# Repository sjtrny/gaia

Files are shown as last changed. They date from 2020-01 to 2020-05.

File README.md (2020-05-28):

# gaia

Gaia is a custom built environment sensor. This repository contains:
- parts list
- required software and setup instructions

## Overview

Gaia provides the following data:
- Ambient Lux
- Local Temperature (near device)
- Local Humidity
- Local Pressure
- Local Gas Resistance (Air Quality)
- Remote Temperature (away from device)

Two I2C sensor are used to collect this data:
- VEML770 (ambient lux)
- BME680 (local readings)
- DS18B20 waterproof (remote temp)

Temperature and Humidity are displayed on an Adafruit LCD.

Gaia runs on [ESPHome](https://esphome.io). See `gaia.yml`  for the configuration of the device.

## AdaFruit RGB LCD Shield

ESPHome does not have an official component for the AdaFruit RB LCD Sheild so I have written a component
for it which you can find in the `custom_components`  folder.

## VEML7700 Support

ESPHome does not have an official component for the VEMl7700 device, so I have written a small device wrapper `veml7700.h`, which leverages the "Adafruit VEML7700 Library".

## Parts List

The parts list can be found in the `parts.xlsx` file.

## Hardware and Wiring

TODO

## Instructions

1. Create virtual environment and install dependencies

```
./setup.sh
```

2. Activate virtual environment

```
source venv/bin/activate
```

3. Add wifi details to  `gaia.yml`

4. Plug in ESP32 via USB

5. Compile and upload to ESP32

```
		esphome gaia.yml run
```

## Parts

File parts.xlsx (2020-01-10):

Unit Price | Count | Total | Name | Link
$14.99 | 1 | $14.99 | ESP32 | https://www.ebay.com.au/itm/AU-ESP-WROOM-32-ESP32-ESP32S-2-4GHz-WiFi-Bluetooth-Development-Board-for-Arduino/303428770355
$36.00 | 1 | $36.00 | Pimoroni BME680 Breakout | https://core-electronics.com.au/bme680-breakout-air-quality-temperature-pressure-humidity-sensor.html
$10.17 | 1 | $10.17 | Adafruit VEML7700 | https://core-electronics.com.au/adafruit-veml7700-lux-sensor-i2c-light-sensor.html
$3.95 | 1 | $3.95 | Cooling Fan for Raspberry Pi | https://core-electronics.com.au/cooling-fan-for-raspberry-pi.html
$3.99 | 1 | $3.99 | 5V Single Channel Relay Module 10A | https://core-electronics.com.au/5v-single-channel-relay-module-10a.html
$6.95 | 1 | $6.95 | IC Experimenters Board | https://www.jaycar.com.au/ic-experimenters-board-140-x-95mm/p/HP9558
$0.95 | 1 | $0.95 | Male Header Strip | https://www.jaycar.com.au/40-pin-header-terminal-strip/p/HM3212
$1.80 | 1 | $1.80 | Female Header Strip | https://www.jaycar.com.au/40-pin-female-header-strip/p/HM3230
$5.95 | 1 | $5.95 | Socker to Socker Leads | https://www.jaycar.com.au/150mm-socket-to-socket-jumper-leads-40-piece/p/WC6026
$14.25 | 1 | $14.25 | Micro USB Power Supply | https://core-electronics.com.au/5v-2a-switching-power-supply-w-20awg-6-microusb-cable.html
$24.85 | 1 | $24.85 | IP67 Clear Cover Enclosure | https://www.ebay.com.au/itm/CLEAR-COVER-HINGED-Lid-IP67-Waterproof-Polycarbonate-Enclosure-Electrical-box/254079017314
 |  | $123.85
 |  | Consumables are not included e.g. heatshrink, solder or small wires

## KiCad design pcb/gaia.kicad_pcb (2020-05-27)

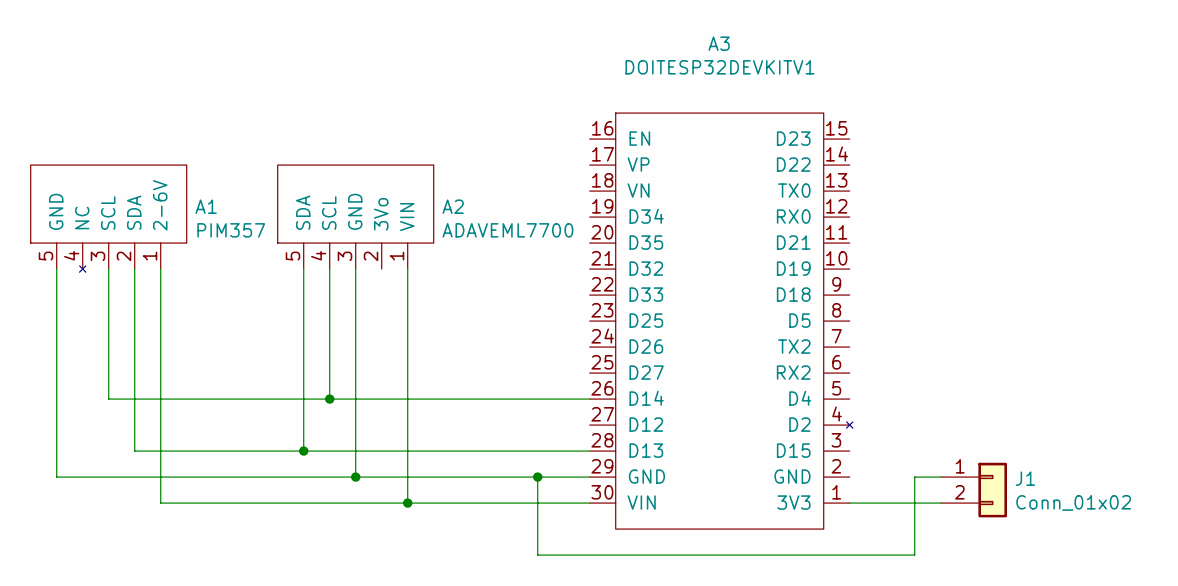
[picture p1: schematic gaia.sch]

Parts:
A1: PIM357
A2: ADAVEML7700
A3: DOITESP32DEVKITV1
J1: Conn_01x02; PinHeader_1x02_P2.54mm_Vertical

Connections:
unnamed: A1.1 (2-6V), A2.1 (VIN), A3.30 (VIN)
unnamed: A1.2 (SDA), A2.5 (SDA), A3.28 (D13)
unnamed: A1.3 (SCL), A2.4 (SCL), A3.26 (D14)
unnamed: A1.5 (GND), A2.3 (GND), A3.29 (GND), J1.1
unnamed: A3.1 (3V3), J1.2

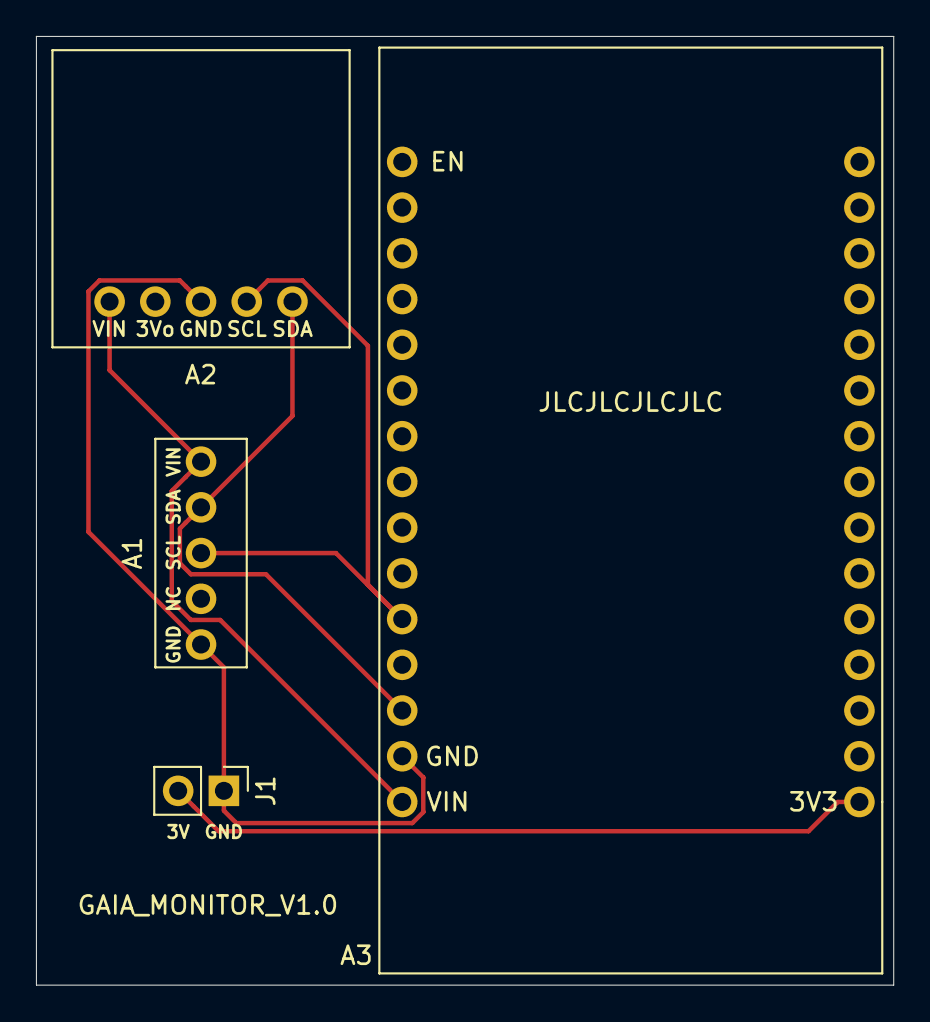
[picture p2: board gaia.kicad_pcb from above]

Board: 2 copper layers, 47.6 x 52.7 mm, 4 parts (0 on the bottom side), 5 nets.

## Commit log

2020-01-06 Initial upload
    [parts.xlsx]
2020-01-10 Migrated to ESPHome
    [parts.xlsx]
2020-05-27 Added PCB, temp probe and LCD
    [gaia.kicad_pcb, gaia.sch]
